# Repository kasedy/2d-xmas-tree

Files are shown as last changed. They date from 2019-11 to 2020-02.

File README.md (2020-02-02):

# 2d-xmas-Tree-art
A DIY flat christmas decoration with a ATtiny25, 20 led´s and a coin cell battery 

## New Features
- Converted to [PlatformIo](https://platformio.org/) project
- Uploading firmware and setting fuses get easier
- Added animation compressing script
- Significantly reduced memory footprint
- More default animations
- Reduced power consumption

## Overview

Image from the 2D xmas tree

This is the only 2-dimensional pcb with all the components embedded into the 1,6mm thick pcb itself.
The components are placed with the help of castellation into the pcb. 

Castellation with component

## PCB

The PCB design is made with KiCad 5.0.1

The PCB should be 1,6mm thick to hide the components inside. Last time I ordered them from [DirtyPCbs](https://dirtypcbs.com/) as suggesed by [@designer2k2](https://github.com/designer2k2). They handle castellation, but you still need to clean metal contacts from bended metalization debris. Next time I'm going to order with [JLCPCB](https://jlcpcb.com/) as I like their bright solder mask color more. To order PCB, use prepared gerber archive [2D_xmas_tree01_gerber_complete.zip](https://raw.githubusercontent.com/kasedy/2d-xmas-tree-art/master/pcb-kicad/gerb/2D_xmas_tree01_gerber_complete.zip)

Most of the PCB is to give it the look of a tree or house, it uses the different color achievable by blending the different layers. Here is a good article on possible colors: https://hackaday.com/2018/06/11/ask-hackaday-what-color-are-your-pcbs/

## Partlist

|ID|#|Ref|Value|Footprint|RS|Digikey|Aliexpress|Img|
| --- | --- | --- | --- | --- | --- | --- | --- | --- |
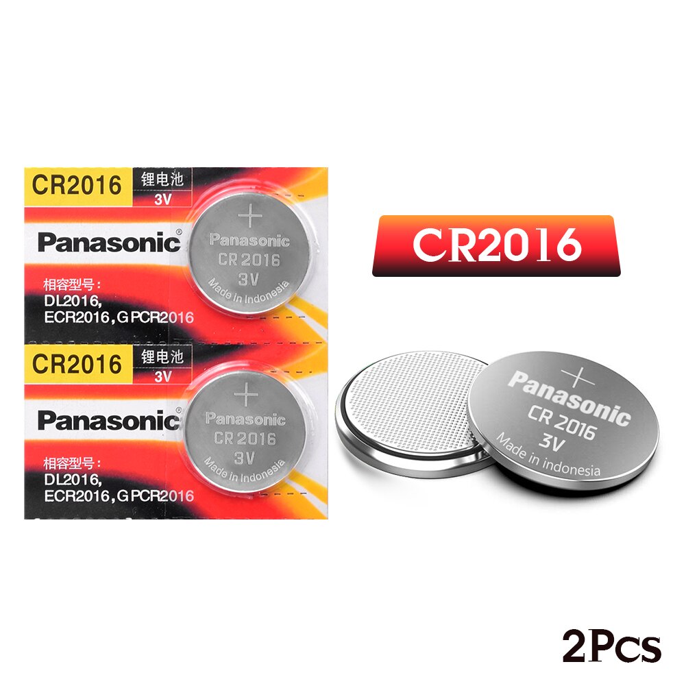
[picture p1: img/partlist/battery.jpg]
|BT|2|BT1-BT2|Battery Cell|CR2016|-|-|[CR2016](https://www.aliexpress.com/item/32865072812.html)||
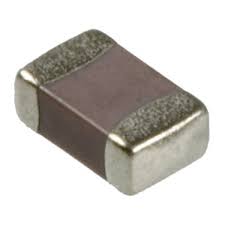
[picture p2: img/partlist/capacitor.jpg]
|C|1|C1|22µF|0805|790-0682|1276-6786-1-ND|[0805 22uF capacitor](https://www.aliexpress.com/item/32374775517.html)||
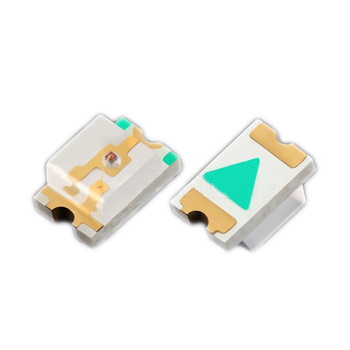
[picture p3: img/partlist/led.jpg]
|D|20|D1-D20|LED|0805|176-6117|516-1431-1-ND|[0805 LED](https://www.aliexpress.com/item/1206476683.html)||
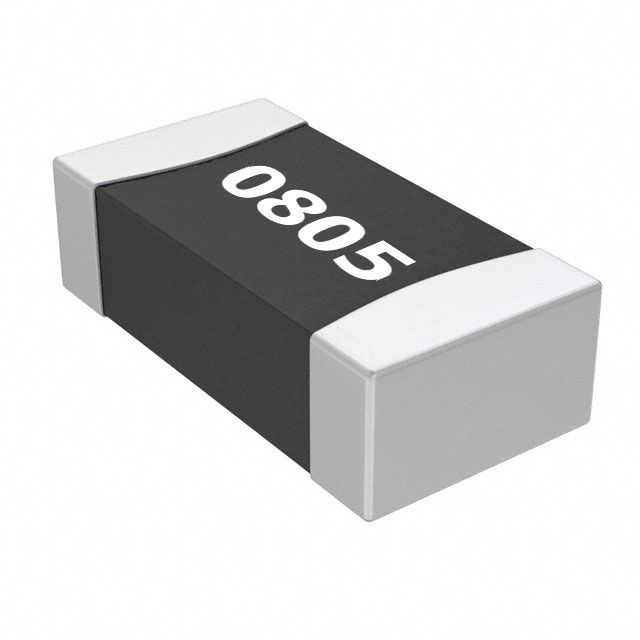
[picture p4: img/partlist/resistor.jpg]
|R|5|R1-R5|see table below|0805|-|RR12Q75DCT-ND|[0805 Resistor](https://www.aliexpress.com/item/32865947306.html)||
|R|1|R6|10k|0805|125-1189|RR12P10.0KDCT-ND|[0805 Resistor](https://www.aliexpress.com/item/32865947306.html)||
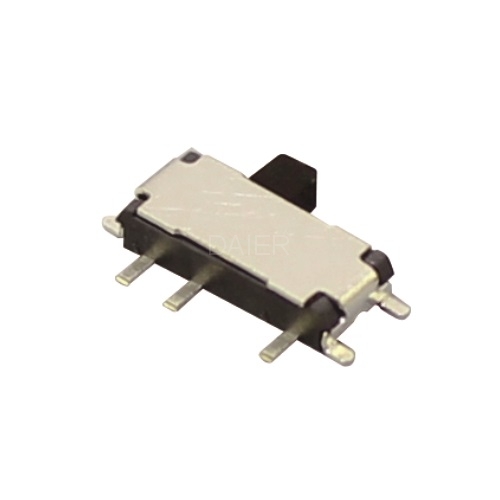
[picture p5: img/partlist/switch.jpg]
|SW|1|SW1|SW_SPDT|PCM12SMTR|793-1721|401-2016-1-ND|[MSK-12C02](https://www.aliexpress.com/item/32863424888.html)||
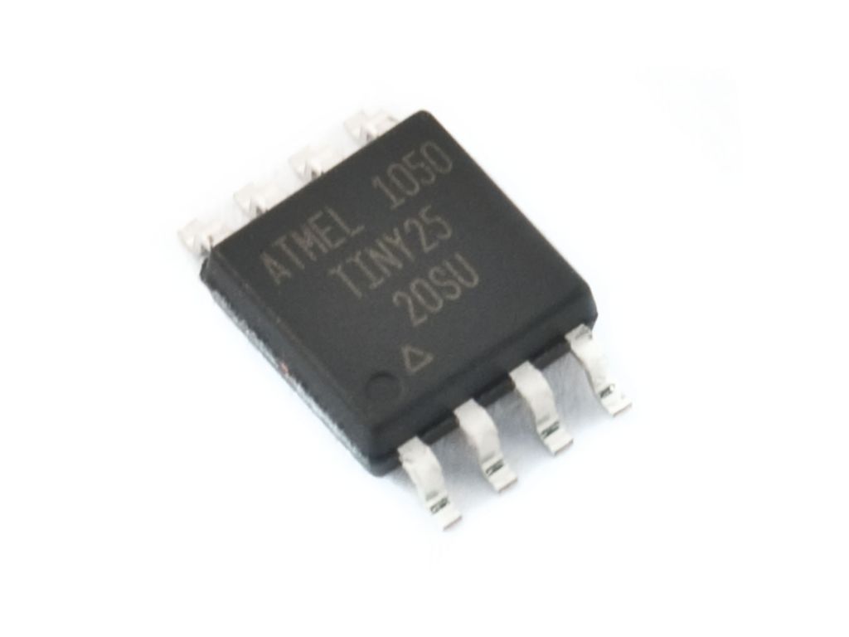
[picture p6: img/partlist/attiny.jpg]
|U|1|U1|ATTINY25-20SU|SOIC8|133-1611|ATTINY25-20SU-ND|-||

ATiny-45 and ATiny-85 will work as well as ATtiny-25 but ATtiny-25 is cheaper and has enough memory to fit the sketch.

## LED

You are free to use any other LED apart proposed above. Please select R1-R5 resistors value according to the table. The lower resistor value the brighter will be LEDs but battery life also will get shorter.

| Nice <br> look | Color | V<sub>min</sub> | V<sub>max</sub> | Non-compensated mode (Ohm) <br> Min - Recomended - Max | Compensated mode (Ohm) <br> Min - Max |
| :---: | :---: | :---: | :---: | :---: | :---: |
| :x: | Red | 1.70 | 2.00 | 150 - 330 - 680 | 30 - 50 |
| :heavy_check_mark: | Yellow | 1.80 | 2.05 | 125 - 180 - 250 | 30 - 50 |
| :heavy_check_mark: | Orange | 1.80 | 2.05 | 125 - 180 - 250 | 30 - 50 |
| :x: | Green | 2.10 | 3.30 | 330 - 680 - 1800 | 30 - 75 |
| :heavy_check_mark: | White | 2.40 | 3.10 | 100 - 470 - 680 | 15 - 60 |
| :heavy_check_mark: | Blue | 2.40 | 3.25 | 100 - 330 - 1000 | 8 - 100 |

In a compensated mode LEDs will have the same brightness regardless how many LEDs are shining. Every enabled LED will shine no more than 1/20 of animation frame time. Resistors should give up to 10-15 mA through a single LED. In non-compensated mode the animation frame with a single LED on will look brighter than an animation with multiple LEDs on. Resistors should give up to 2-4 mA current through a single LED. Non-compensated brightness mode is a default as it gives almost the same brightness for animation frames with high number LEDs enabled, but frames with low number active LEDs look much brighter for the same current consumption from a battery. To change the mode update value of COMPENSATED_BRIGHTNESS flag.

## Assembly

Assembly might be a little challenging. The full process can be seen in this [youtube video](https://www.youtube.com/watch?v=K6z7--RqQHQ). I'll mention here only the tricky parts.

Solder the LED oriented with the cathode to the line, like it's shown on the picture. If you by some reason soldered LEDs upside down and animation looks weird, set REVERSED_LEDS flag to "true" when compile the firmware.

LED orientation

The ATtiny feet needs to be trimmed very closely to the body to fit it inside the cutout.

ATtiny soldered with trimmed feet

Use very thin wire to create a kind of spider web for the battery, but don't shortcut it!

Battery wire web

Then use some tape to secure it in place.

Battery mounted in place

## Upload Firmware

- Install [PlatformIo](https://platformio.org/)
- Download and open the project at "firmware" directory
- Connect ISP programmer head
- Run "Set Fuses" and "Upload" under "attiny25_1MHz" build rule

To program ATtiny microcontroller ISP programmer is needed. For example an open-source [USB ASP](https://www.fischl.de/usbasp/). As an alternative some Arduinos can be converted to a ISP programmer with ArduinoISP https://www.arduino.cc/en/Tutorial/ArduinoISP.

Arduino as ISP to programm the 2d xmas tree

ISP Pinout:

ISP Pinout

ISP pinout in PCB

## Create your own animation!

Use [graphical interface](https://kasedy.github.io/2d-xmas-tree-art/) to create unique animation. Copy every frame value into [animation.txt](firmware/src/animation.txt). After animation is ready compile and upload the firmware.

GUI demonstration (https://kasedy.github.io/2d-xmas-tree-art/)

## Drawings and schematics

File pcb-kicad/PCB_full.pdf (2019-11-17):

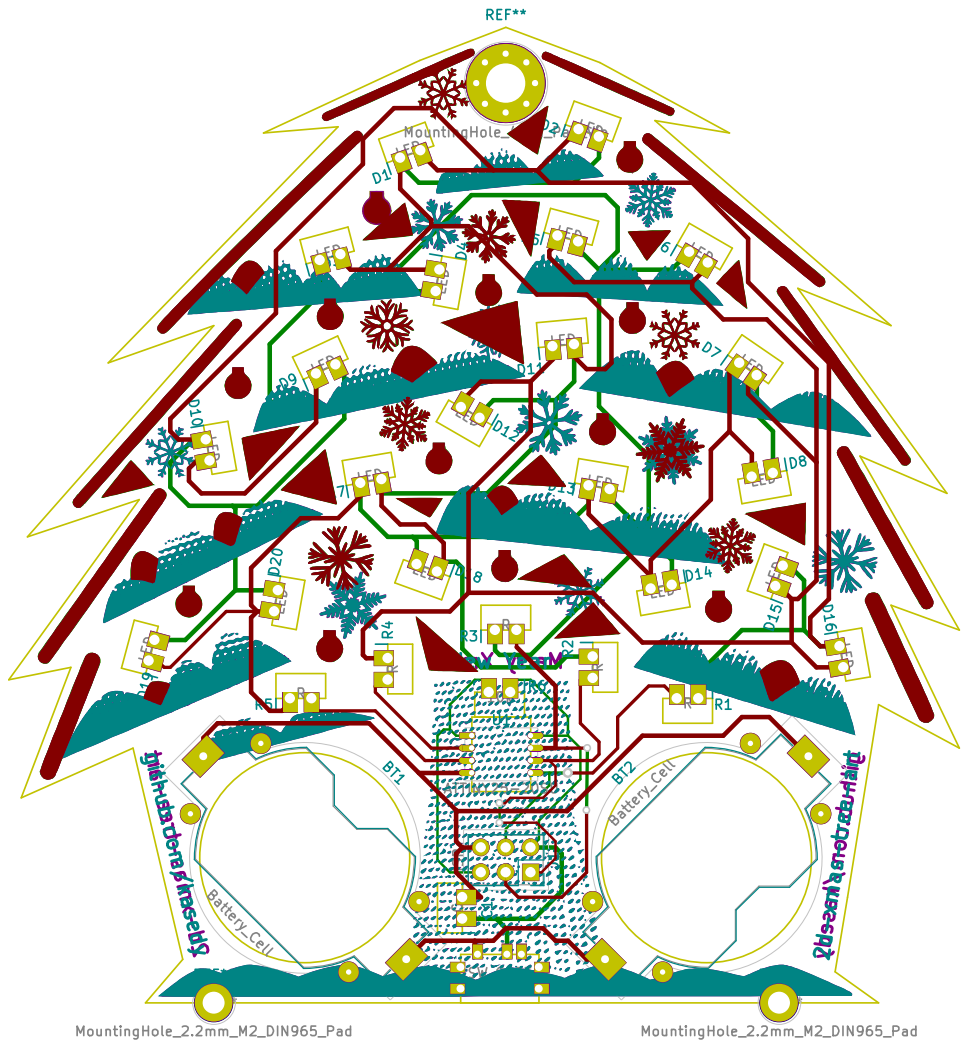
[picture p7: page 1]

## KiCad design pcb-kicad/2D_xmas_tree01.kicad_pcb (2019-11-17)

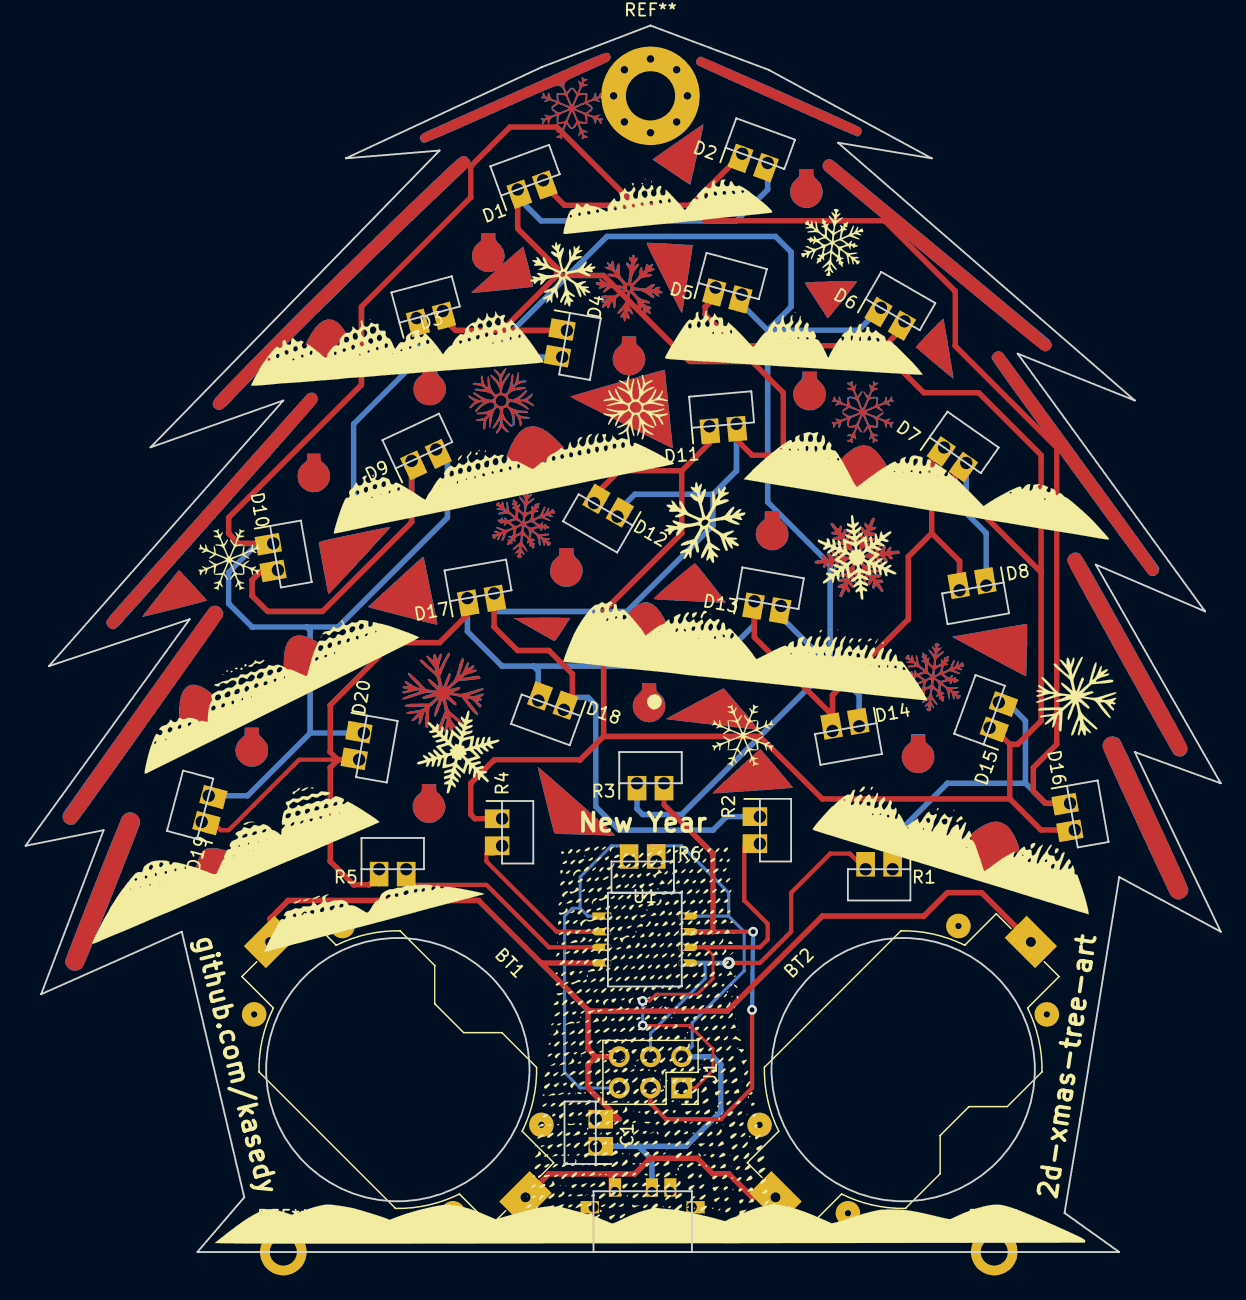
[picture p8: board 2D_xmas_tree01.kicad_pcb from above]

Board: 2 copper layers, 97.2 x 99.7 mm, 32 parts (0 on the bottom side), 14 nets.

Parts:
BT1, BT2: Battery_Cell; Keystone_1058_1x2032-CoinCell_Inside
C1: C; 0805_Internal_Castellation
D1, D2, D3, D4, D5, D6, D7, D8, D9, D10, D11, D12, D13, D14, D15, D16, D17, D18, D19, D20: LED; 0805_Internal_Castellation
J1: ISP; Socket_Strip_Straight_2x03_Pitch2.54mm
R1, R2, R3, R4, R5: R; 0805_Internal_Castellation
R6: 10k; 0805_Internal_Castellation
SW1: SW_SPDT; PCM12SMTR_inside
U1: ATTINY25-20SU; SOIC-8_Inside

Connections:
/MISO: J1.1, R2.2, U1.6
/MOSI: J1.4, R1.2, U1.5
/RESET: J1.5, R6.2, U1.1
/SCK: J1.3, R3.2, U1.7
/VCC: C1.1, J1.2, R6.1, SW1.2, U1.8
GND: BT1.2, BT2.2, C1.2, J1.6, U1.4
unnamed: BT1.1, BT2.1, SW1.1
unnamed: D1.1, D2.2, D3.2, D4.1, D11.2, D12.1, D17.2, D18.1, R2.1
unnamed: D1.2, D2.1, D9.2, D10.1, D15.2, D16.1, D19.2, D20.1, R1.1
unnamed: D3.1, D4.2, D5.2, D6.1, D9.1, D10.2, D13.2, D14.1, R3.1
unnamed: D5.1, D6.2, D7.2, D8.1, D11.1, D12.2, D15.1, D16.2, R4.1
unnamed: D7.1, D8.2, D13.1, D14.2, D17.1, D18.2, D19.1, D20.2, R5.1
unnamed: R4.2, U1.2
unnamed: R5.2, U1.3

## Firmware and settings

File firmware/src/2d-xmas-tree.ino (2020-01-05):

/* 
  2D XMAS Tree Code
  charlieplexing christmas decoration
  5 Pins with 20 LED´s

  Designed by:

    https://www.designer2k2.at

  Enhanced by:

    https://github.com/kasedy

      1. Converted to PlatformIo project for ease run animation compressing script and setting fusses
      2. More animations
      3. Significantly reduced memory footprint
      4. Improved power consumption optimizations

  MIT License

  Copyright (c) [2018] [Stephan Martin]

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
  THE SOFTWARE IS PROVIDED "AS IS", WITHOUT WARRANTY OF ANY KIND, EXPRESS OR
  IMPLIED, INCLUDING BUT NOT LIMITED TO THE WARRANTIES OF MERCHANTABILITY,
  FITNESS FOR A PARTICULAR PURPOSE AND NONINFRINGEMENT. IN NO EVENT SHALL THE
  AUTHORS OR COPYRIGHT HOLDERS BE LIABLE FOR ANY CLAIM, DAMAGES OR OTHER
  LIABILITY, WHETHER IN AN ACTION OF CONTRACT, TORT OR OTHERWISE, ARISING FROM,
  OUT OF OR IN CONNECTION WITH THE SOFTWARE OR THE USE OR OTHER DEALINGS IN THE
  SOFTWARE.
*/

#include "helpers.h"

#include <avr/pgmspace.h>
#include <util/delay.h>

#define NUM_LEDS 20

#if !defined(COMPILED_ANIMATION) && !defined(ANIMATION_END_FRAMES)
  #define COMPILED_ANIMATION {\
    0x03, 0x00, 0xC0, 0x03, 0x00, 0x40, 0x0D, 0x00, \
    0x28, 0x11, 0x00, 0xE0, 0x0E, 0x00, 0x40, 0x04, \
    0x01, 0x93, 0x80, 0x00, 0xE0, 0x20, 0x00, 0x00, \
    0x0C, 0x12, 0x14, 0x40, 0x10, 0x30, 0x00, 0x02, \
    0x08, 0x00, 0x40 \
  }
  #define ANIMATION_END_FRAMES {14}
#endif

static const uint8_t animation[] PROGMEM = COMPILED_ANIMATION;
static const uint16_t animationEndFrames[] = ANIMATION_END_FRAMES;
static uint8_t currentAnimation = 0;

// Light every led in order after power on. Good to test quality of soldering.
#define SHOW_TEST_ANIMATION_AT_START false

// The delay in ms between the Frames when displaying preprogramed animation.
#define ANIMATION_FRAME_TIME 500

// Intro time (how long the random change happens) in ms:
#define STARTS_ANIMATION_TIME_MS 10000

// If you soldered LED upside down and animation looks weird set this flag to "true".
#define REVERSED_LEDS false

// LEDs will have the same brightness regardles how many LEDs are on. Every enabled LED 
// will shine no more than 1/20 of animation frame time. Resistors should give 10-15 mA 
// through a single LED. If the flag set to "false" animation frames with a single LED 
// on will be brighter than when multiple leds are on. Resistors should give 2-4 mA 
// current through a single LED.
#define COMPENSATED_BRIGHTNESS false

// This holds the pin configuration to make the 20 led charlieplexing.
struct LedControlPin {
  #if REVERSED_LEDS
    uint8_t pgnd : 4;
    uint8_t pvcc : 4;
  #else
    uint8_t pvcc : 4;
    uint8_t pgnd : 4;
  #endif
};

const LedControlPin ledControlPins[] = {
  {0, 1},
  {1, 0},
  {1, 2},
  {2, 1},
  {2, 3},
  {3, 2},
  {3, 4},
  {4, 3},
  {0, 2},
  {2, 0},
  {1, 3},
  {3, 1},
  {2, 4},
  {4, 2},
  {0, 3},
  {3, 0},
  {1, 4},
  {4, 1},
  {0, 4},
  {4, 0},
};

// Placeholder for all current leds.
uint8_t ledstate[NUM_LEDS] = {};

void setup() {
  // Disable ADC (power saving):
  ADCSRA = 0;

  // Shut down Timer/Counter1, Timer/Counter0, ISI, ADC
  PRR = 1;

  #if SHOW_TEST_ANIMATION_AT_START
    testAnimation();
  #endif
}

void loop() {
  showStarsAnimation();
  showNextPreprogrammedAnimation();
}

void testAnimation() {
  // Show all leds
  for (int i = 0; i < NUM_LEDS; ++i) {
    ledstate[i] = 1;
  }
  showleds(2000);

  // Show single led in order
  for (int i = 0; i < NUM_LEDS; ++i) {
    for (int j = 0; j < NUM_LEDS; ++j) {
      ledstate[j] = i == j ? 1 : 0;
    }
    showleds(400);
  }

  // Show none
  extinguish();
  _delay_ms(1000);
}

uint16_t fastRandom() {
  static uint16_t seed = 0xBEEF;
  seed = (seed * 2053 + 13849) % 65536;
  return seed;
}

void showStarsAnimation() {
  // Every 25ms change a random led to a random state.
  // Extingush command makes LEDs flikering.
  unsigned long instroStartTime = millis();
  while (millis() - instroStartTime < STARTS_ANIMATION_TIME_MS) {
    uint16_t randomValue = fastRandom();
    int ledtoset = randomValue % NUM_LEDS;
    bool ledbool = randomValue & 0b10000000;
    ledstate[ledtoset] = ledbool ? 1 : 0;
    showleds(25);
    extinguish();
    #if F_CPU >= 1000000L
      _delay_ms(2);
    #endif
  }
}

void showNextPreprogrammedAnimation() {
  if (ARRAY_LEN(animationEndFrames) == 0) {
    return;
  }

  uint16_t startFrame = 0;
  if (currentAnimation != 0) {
    startFrame = animationEndFrames[currentAnimation - 1];
  }
  uint16_t endFrame = animationEndFrames[currentAnimation];

  // Show preprogrammed animation.
  for (uint16_t iFrame = startFrame; iFrame < endFrame; ++iFrame) {
    uint16_t startBitPosition = iFrame * NUM_LEDS;
    uint8_t byteIndex = startBitPosition / 8;
    uint8_t bitIndex = startBitPosition % 8;
    uint8_t state = pgm_read_byte(animation + byteIndex);
    for (int i = 0; i < NUM_LEDS; ++i) {
      if (bitIndex == 8) {
        bitIndex = 0;
        byteIndex += 1;
        state = pgm_read_byte(animation + byteIndex);
      }
      ledstate[i] = (state & (1 << bitIndex)) ? 1 : 0;
      bitIndex += 1;
    }
    showleds(ANIMATION_FRAME_TIME); 
  }

  if (++currentAnimation >= ARRAY_LEN(animationEndFrames)) {
    currentAnimation = 0;
  }
}

//-------------------------------------------------------------------------------------

void showleds(unsigned int showTimeMs) {
  // This cycles trough all the LEDs in the array and show them one-by-one. That 
  // happens so quickly that human eye sees like LEDs shine all together.
  unsigned long startTime = millis();
  while (true) {
    for (int i = 0; i < NUM_LEDS; i++) {
      showled(i);
    }
    if (millis() - startTime > showTimeMs) {
      return;
    }
  }
}

void showled(uint8_t led) {
  // It should 1 if LED is enabled or 0 if disabled.
  uint8_t ledOn = ledstate[led];

  #if !COMPENSATED_BRIGHTNESS
    if (!ledOn) {
      return;
    }
  #endif

  // Lookup the pin for high and low:
  const LedControlPin &pinouts = ledControlPins[led];

  // Set pins that contold LED to output. The other pins will be set to input.
  DDRB = (ledOn << pinouts.pvcc) | (ledOn << pinouts.pgnd);

  // Write the status.
  PORTB = (ledOn << pinouts.pvcc); // set HIGH

  // Dont extinguish. Let LED shine while microcontroller decides which LED to 
  // light next.
}

void extinguish() {
  // This tristates all pins
  DDRB = 0; // Input state for pins 0-4 pins
  PORTB = 0; //ensure pullups are off.
}

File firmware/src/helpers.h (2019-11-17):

#pragma once

#define COMPILE_TIME_SIZEOF(t)      template<int s> struct SIZEOF_ ## t ## _IS; \
                                    struct foo { \
                                        int a,b; \
                                    }; \
                                    SIZEOF_ ## t ## _IS<sizeof(t)> SIZEOF_ ## t ## _IS;


/* definition to expand macro then apply to pragma message */
#define VALUE_TO_STRING(x...) #x
#define VALUE(x...) VALUE_TO_STRING(x)
#define VAR_NAME_VALUE(var) #var "="  VALUE(var)

// #pragma message(VAR_NAME_VALUE(COMPILED_ANIMATION))

#if F_CPU == 500000L // X16
  #define CPU_PRESCALER_BITS (1 << CLKPS2)
#elif F_CPU == 250000L // X32
  #define CPU_PRESCALER_BITS (1 << CLKPS2) | (1 << CLKPS0)
#elif F_CPU == 125000L // X64
  #define CPU_PRESCALER_BITS (1 << CLKPS2) | (1 << CLKPS1)
#elif F_CPU == 62500 // X128
  #define CPU_PRESCALER_BITS (1 << CLKPS2) | (1 << CLKPS1) | (1 << CLKPS0)
#elif F_CPU == 31250 // X256
  #define CPU_PRESCALER_BITS (1 << CLKPS3)
#endif

#ifdef CPU_PRESCALER_BITS
  #define SET_CPU_PRESCALER() \
    cli(); \
    CLKPR = (1 << CLKPCE); /* Clock prescaler change enable*/ \
    CLKPR = (CPU_PRESCALER_BITS); \
    sei();
#else
  #define SET_CPU_PRESCALER()
#endif

#define ARRAY_LEN(x) (sizeof(x) / sizeof(*x))

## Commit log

2019-10-26 Replaced 2018 year on a silk with "Merry Xmas"
    [2D_xmas_tree01.kicad_pcb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]
2019-11-16 Reduced memory footprint to: 1624 bytes / 53 byts
2019-11-16 * Reduced memory footprint to: 1582 bytes / 53 byts
2019-11-16 Reduced memory footprint to: 1558 bytes / 53 byts
2019-11-16 Reduced memory footprint to: 1343 bytes / 53 byts
2019-11-16 Improved power saving
2019-11-16 Reduced memory footprint to: 1334 bytes / 53 byts
2019-11-16 Measured power consumption. Update the documents.
2019-11-17 1. added fastRandom to reduce flickering and memory footprint 2. added 2 new animation 3. More comments
2019-11-17 Changed silk layer to include name of the project that anyone who get the pcb know where to find firmware update
    [2D_xmas_tree01.kicad_pcb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]
2019-11-29 Added test animation on the startup. Added flag in REVERSED_LEDS to set true in case if you soldered LED upside down.
    [2d-xmas-tree.ino]
2019-12-01 added COMPENSATED BRIGHTNESS LED mode
2019-12-02 added Resistor value table
2019-12-22 Added part list image for 0805 capacitor
2020-02-03 added ArduinoISP to configuration
